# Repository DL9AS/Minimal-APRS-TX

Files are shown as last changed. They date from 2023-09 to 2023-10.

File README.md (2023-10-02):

# Minimal APRS TX by DL9AS

**Note: This project is still in active development. There is no guarantee for full functionality at this time!**

The goal of this project is to provide one of the simplest APRS transmitters. It is especially designed for people who are starting high altitude ballooning. If you are interested in more advanced APRS radiosondes with camera, please have a look at this repository: https://github.com/DL9AS/jufo-project-radiosonde

The PCB requires only five components. The transmitter can be controlled with simple serial commands.

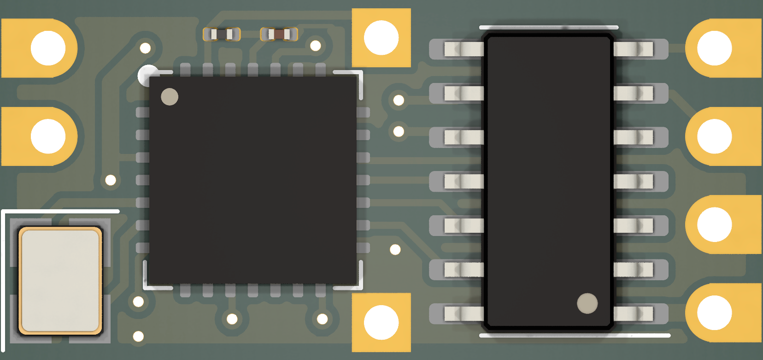
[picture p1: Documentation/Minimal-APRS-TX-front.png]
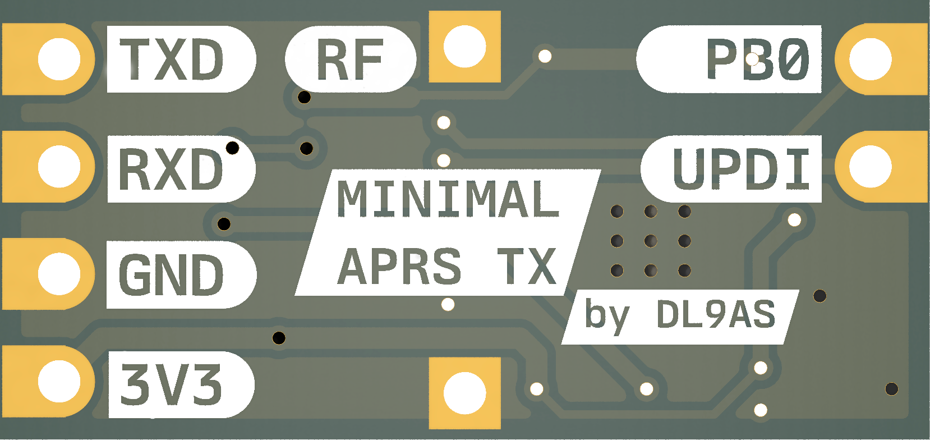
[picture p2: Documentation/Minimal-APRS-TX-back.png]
|  |  |
|:--- |:--- |

## Table of contents

- [Minimal APRS TX by DL9AS](#minimal-aprs-tx-by-dl9as)
  - [Table of contents](#table-of-contents)
  - [Usage](#usage)
    - [`$STAT` *(Get status)*](#stat-get-status)
    - [`$CfgRadio` *(Configure APRS radio)*](#cfgradio-configure-aprs-radio)
    - [`$TxPosPkt` *(Transmit APRS position packet)*](#txpospkt-transmit-aprs-position-packet)
    - [`$TxStatPkt` *(Transmit APRS status packet)*](#txstatpkt-transmit-aprs-status-packet)
  - [PCB Assembly](#pcb-assembly)
  - [Programming](#programming)

## Usage

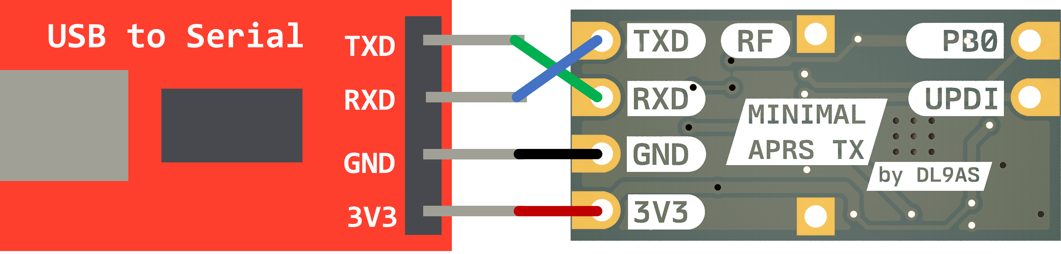
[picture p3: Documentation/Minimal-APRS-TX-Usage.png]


Only a few commands are required to use the Minimal APRS TX module. First the radio is configured with the command `$CfgRadio` and then APRS packets can be sent with the commands `$TXPosPkt` or `$TXStatPkt`.

For communication `9600 Baud` serial with 8 data bits, no parity, one stop bit is used. So it should communicate out of the box with any Arduino.

### `$STAT` *(Get status)*

```
Format:
$STAT;

Return:
[ACK] Minimal APRS TX - V1.0
```

### `$CfgRadio` *(Configure APRS radio)*

```
Format:
$CfgRadio <APRS_Freq>,<APRS_Freq_Err>,<TX_PWR>,<Afsk_Tone>,<Freq_Dev>,<Src_Call>,<Src_ID>,<Digi_Call>,<Digi_SSID>;

Example:
$CfgRadio 144800000,0,17,205,2700,DL9AS,11,WIDE1,1;
```

- `<APRS_Freq>` - APRS frequency in Hz (e.g. `144800000`)
- `<APRS_Freq_Err>` - APRS frequency error/offset in Hz (e.g. `0`)
- `<TX_PWR>` - Transmission power from 2dbm to 20dbm (e.g. `17`)
- `<Afsk_Tone>` - AFSK tone adjustment (e.g. `205`)
- `<Freq_Dev>` - FSK deviation in Hz (e.g. `2700`)
- `<Src_Call>` - APRS source callsign (e.g. `DL9AS`)
- `<Src_ID>` - APRS source SSID (e.g. `11`)
- `<Digi_Call>` - APRS digipeater path callsign (e.g. `WIDE1`)
- `<Digi_SSID>` - APRS digipeater path SSID (e.g. `1`)

### `$TxPosPkt` *(Transmit APRS position packet)*

```
Format:
$TxPosPkt <Lat>,<Long>,<Alt>,<Symbol>,<Symbol_Overlay>,<Comment>;

Example:
$TxPosPkt 525121,133273,42,O,/,"73 from DL9AS";

Resulting APRS packet:
DL9AS-11>AMON,WIDE1-1:!5230.72N/01319.63EO/A=000137/N0T26V31 73 from DL9AS
```

- `<Lat>` - GPS Latitude in deg * 10000 (e.g. `525121`)
- `<Long>` - GPS Longitude in deg * 10000 (e.g. `133273`)
- `<Alt>` - GPS Altitude in meters (e.g. `42`)
- `<Symbol>` - APRS symbol (e.g. `O` for balloon)
- `<Symbol_Overlay>` - APRS symbol overlay (e.g. `/` for balloon)
- `<Comment>` - APRS comment with 50 character max (e.g. `"73 from DL9AS"`)

Note: `(N<Pkt_count>T<Temperature>V<VCC*10>)` is automatically added to the final packet.

### `$TxStatPkt` *(Transmit APRS status packet)*

```
Format:
$TxStatPkt <Comment>;

Example:
$TxStatPkt "73 from DL9AS";

Resulting APRS packet:
DL9AS-1>AMON,WIDE1-1:>N0T0V31 73 from DL9AS
```

- `<Comment>` - APRS comment with 80 character max (e.g. `"73 from DL9AS"`)

Note: `(N<Pkt_count>T<Temperature>V<VCC*10>)` is automatically added to the final packet.

## PCB Assembly

<table>
  <tr>
    <td>In a first step, with the help of the <a href="Hardware/Gerber-Files/">gerber files</a>
, the custom PCBs are ordered from a PCB manufacturer. I would also recommend to order a stencil, that makes the soldering easier.</td>
    <td></td>
  </tr>
</table>

The needed components can now be ordered:

| Designator | Part | Quantity | Price (09.2023) |
| --- | --- | --- | --- |
| U1 | ATTiny1604 | 1 | 0.81$ |
| U2 | SX1278IMLTRT | 1 | 2.65$ |
| X1 | 32MHz Crystal (SMD3225 package) | 1 | 0.15$ |
| C1 | 100nF (0402 package) | 1 | 0.01$ |
| L1 | 200nH (0402 package) | 1 | 0.01$ |

With the PCBs and the components, the transmitter can now be assembled. I would recommend reflow soldering with stencil. It is important that the correct orientation of the ICs is ensured. This [interactive BOM](https://htmlpreview.github.io/?https://github.com/DL9AS/Minimal-APRS-TX/blob/main/Hardware/InteractiveBOM.html) can help with placing the components.

## Programming

Before the Minimal APRS TX module can be used, the ATTiny1604 microcontroller has to be programmed. Here the firmware can be built from the source code or the ready binaries can be used. To keep these instructions as simple as possible, I will describe the second option.

1. First you want to install the `pymcuprog` utility. This requires Python and can be done using `pip install pymcuprog`.  See https://pypi.org/project/pymcuprog/ for more information.
2. Download the correct firmware binary from [here](Software/Binaries/).
3. Connect the USB to serial adapter and install serial drivers if necessary.
4. Run the following command to upload the firmware: 

```
pymcuprog write -d attiny1604 -t uart --erase --verify -u <PORT> -f <FIRMWARE>
```

- `<PORT>` - Serial Port (e.g. `COM5` or `ttyACM0`)
- `<FIRMWARE>` - Firmware file (e.g. `Minimal-APRS-TX_V1.0.hex`)

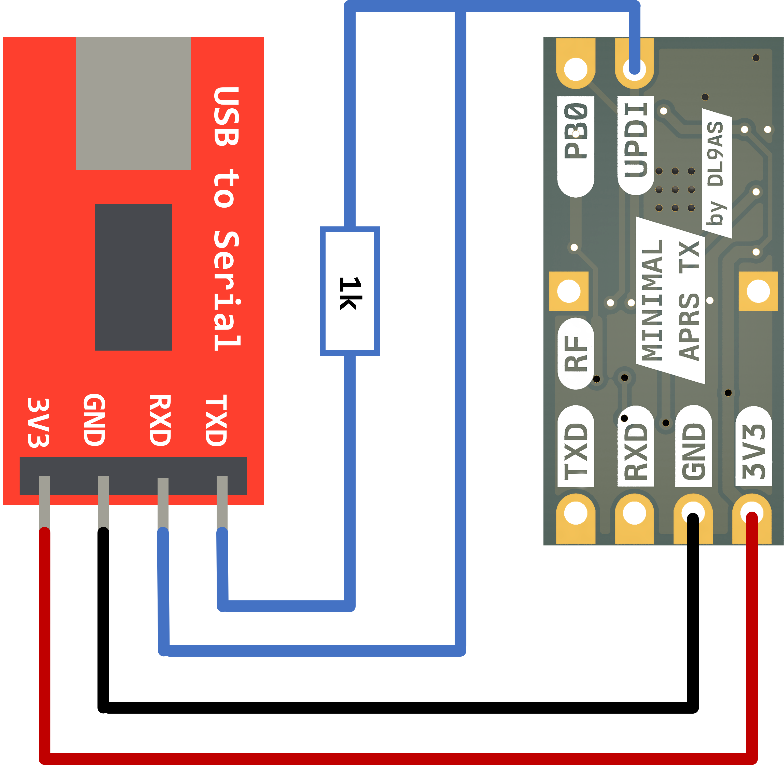
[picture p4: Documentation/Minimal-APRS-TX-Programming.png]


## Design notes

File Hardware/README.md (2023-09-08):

# Minimal APRS TX by DL9AS



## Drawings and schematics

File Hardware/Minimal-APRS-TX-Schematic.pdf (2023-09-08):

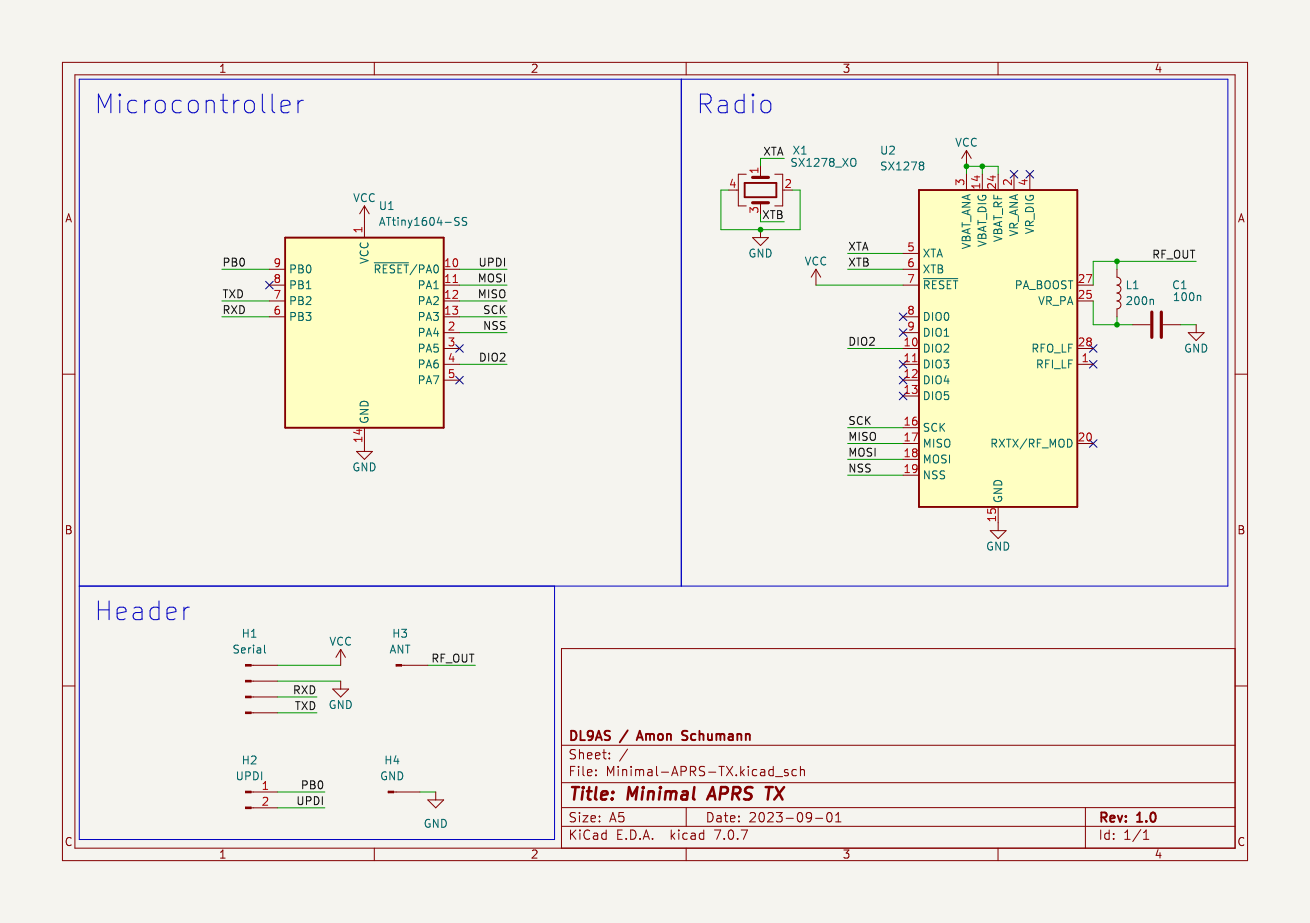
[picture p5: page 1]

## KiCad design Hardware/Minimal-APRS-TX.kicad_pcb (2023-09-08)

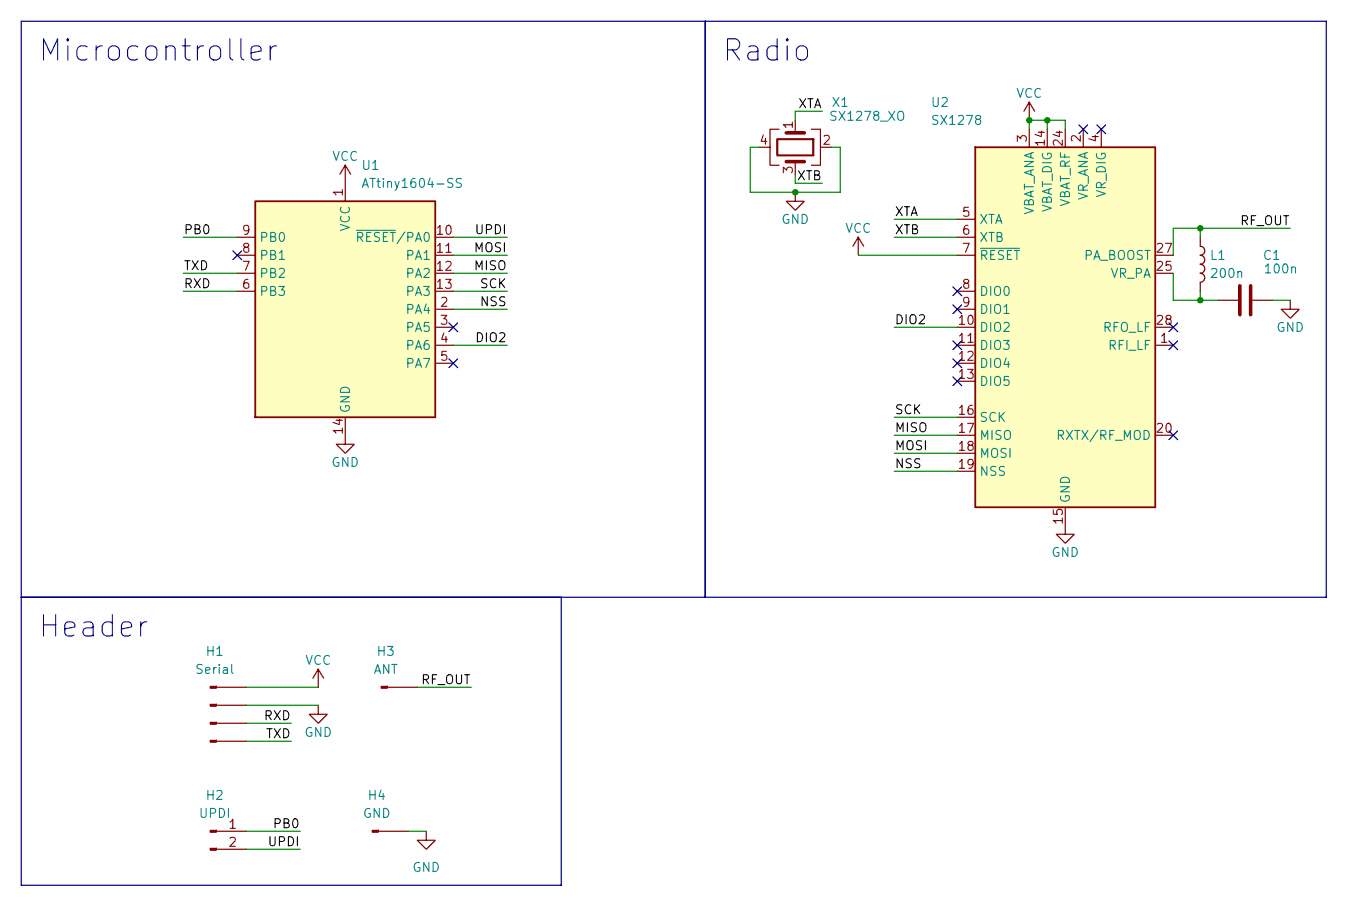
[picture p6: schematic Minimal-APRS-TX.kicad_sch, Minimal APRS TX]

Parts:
C1: 100n; C_0201_0603Metric
H1: Serial; My_PinHeader_4
H2: UPDI; My_PinHeader_2
H3: ANT; My_ANT_Pad
H4: GND; My_ANT_Pad
L1: 200n; L_0201_0603Metric
U1: ATtiny1604-SS; SOIC-14_3.9x8.7mm_P1.27mm
U2: SX1278; QFN-28-1EP_6x6mm_P0.65mm_EP4.8x4.8mm
X1: SX1278_XO; Crystal_SMD_3225-4Pin_3.2x2.5mm

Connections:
/DIO2: U1.4 (PA6), U2.10 (DIO2)
/MISO: U1.12 (PA2), U2.17 (MISO)
/MOSI: U1.11 (PA1), U2.18 (MOSI)
/NSS: U1.2 (PA4), U2.19 (NSS)
/PB0: H2.1, U1.9 (PB0)
/RF_OUT: H3.1, L1.1, U2.27 (PA_BOOST)
/RXD: H1.3, U1.6 (PB3)
/SCK: U1.13 (PA3), U2.16 (SCK)
/TXD: H1.4, U1.7 (PB2)
/UPDI: H2.2, U1.10 (~RESET/PA0)
/XTA: U2.5 (XTA), X1.1
/XTB: U2.6 (XTB), X1.3
GND: C1.2, H1.2, H4.1, U1.14 (GND), U2.15 (GND), U2.21 (GND), U2.22 (GND), U2.23 (GND), U2.26 (GND), U2.29 (GND), X1.2, X1.4
unnamed: C1.1, L1.2, U2.25 (VR_PA)
VCC: H1.1, U1.1 (VCC), U2.3 (VBAT_ANA), U2.7 (~RESET), U2.14 (VBAT_DIG), U2.24 (VBAT_RF)

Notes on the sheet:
Microcontroller
Radio
Header

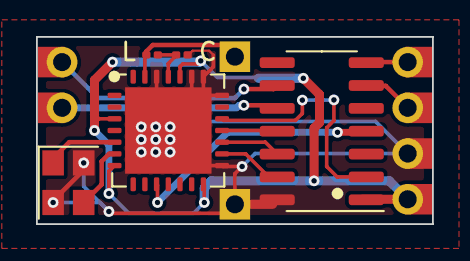
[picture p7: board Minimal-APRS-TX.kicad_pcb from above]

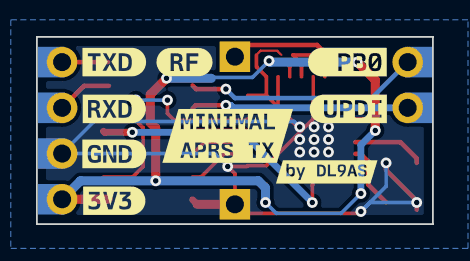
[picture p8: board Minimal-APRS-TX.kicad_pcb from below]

Board: 2 copper layers, 22.0 x 10.4 mm, 18 parts (9 on the bottom side), 15 nets.

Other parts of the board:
kibuzzard-64F1B3B3: G***; kibuzzard-64F1B3B3
kibuzzard-64F1B32F: G***; kibuzzard-64F1B32F
kibuzzard-64F1B34A: G***; kibuzzard-64F1B34A
kibuzzard-64F1B328: G***; kibuzzard-64F1B328
kibuzzard-64F1B334: G***; kibuzzard-64F1B334
kibuzzard-64F1B338: G***; kibuzzard-64F1B338
kibuzzard-64F1B350: G***; kibuzzard-64F1B350
kibuzzard-64F18FB8: G***; kibuzzard-64F18FB8
kibuzzard-64F18FF4: G***; kibuzzard-64F18FF4

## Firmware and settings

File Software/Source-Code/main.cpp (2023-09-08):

/*
 * This file is part of the Minimal APRS TX project.
 * 
 
 * Copyright (C) 2023  Amon Schumann / DL9AS
 
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
 * You should have received a copy of the GNU General Public License
 * along with this program. If not, see <http://www.gnu.org/licenses/>.
 */ 

#include "config.h"
#include "globals.h"
#include "aprs.h"
#include "ax25.h"
#include "SX1278.h"
#include "voltage.h"

// Module globals
uint16_t aprs_packet_counter = 0;

// APRS configuration
uint64_t APRS_freq = SX1278_FREQUENCY;
int32_t APRS_freq_err = SX1278_FREQUENCY_CORRECTION;
uint8_t TX_pwr = SX1278_TX_POWER;
uint32_t FSK_deviation = SX1278_DEVIATION;
char Src_call[8] = APRS_SOURCE_CALLSIGN;
uint8_t Src_ssid = APRS_SOURCE_SSID;
char Digi_call[8] = APRS_DIGIPEATER;
uint8_t Digi_ssid = APRS_DIGIPEATER_SSID;

// APRS Position packets tmp
int32_t latitude = 0;
int32_t longitude = 0;
int32_t altitude = 0;
char latitude_DMH[9];
char longitude_DMH[10];
char comment[81] = "";
char symbol = APRS_SYMBOL;
char symbol_overlay = APRS_SYMBOL_OVERLAY;

// Module functions
void main_generate_aprs_position_packet();
void main_generate_aprs_status_packet();
void convert_gps_coordinates_to_DMH(int32_t gps_latitude, int32_t gps_longitude, char* gps_latitude_DMH, char* gps_longitude_DMH);

void setup()
{
  WDT_INIT;

  // Enable or disable debug serial
  #ifdef DEBUG_SERIAL_ENABLE
    Serial.begin(DEBUG_SERIAL_BAUD_RATE);
  #endif

  // Begin SX1278
  SX1278_begin();

  // Set unused Pins to INPUT_PULLUP for power savings
  pinMode(1, INPUT_PULLUP );
  pinMode(3, INPUT_PULLUP );
  pinMode(6, INPUT_PULLUP );
  pinMode(7, INPUT_PULLUP );
  pinMode(11, INPUT_PULLUP );

  DEBUG_PRINTLN("[STAT]: booted");
}

void loop()
{

  char serial_command_buffer[100]; // TODO: Check size requirements
  memset(serial_command_buffer, '\0', 100);

  while (Serial.available() == false) {WDT_RESET;} // Wait for serial data

  Serial.readBytesUntil(';', serial_command_buffer, 150);

  DEBUG_PRINT("[RCV]: ");
  DEBUG_PRINTLN(serial_command_buffer);

  uint8_t status;

  // Parse $STAT command
  if (!strcmp(serial_command_buffer, "$STAT"))
  {
    DEBUG_PRINTLN("[ACK]: Minimal APRS TX - V1.0");
  }

  // Parse $CfgRadio command
  else if ((status = sscanf(serial_command_buffer, "$CfgRadio %lu,%ld,%hhu,%hhu,%lu,%[^,],%hhu,%[^,],%hhu", &APRS_freq, &APRS_freq_err, &TX_pwr, &AFSK_tone_adj_space, &FSK_deviation, Src_call, &Src_ssid, Digi_call, &Digi_ssid)))
  {
    if(status == 9)
    {
      DEBUG_PRINTLN("[ACK]: valid $CfgRadio");
      AFSK_tone_adj_mark = AFSK_tone_adj_space * 2;
    }
    else
    {
      DEBUG_PRINTLN("[ERR]: invalid $CfgRadio");
    }
  }

  // Parse $TxPosPkt command
  else if ((status = sscanf(serial_command_buffer, "$TxPosPkt %ld,%ld,%ld,%c,%c,\"%[^\"]", &latitude, &longitude, &altitude, &symbol, &symbol_overlay, comment)))
  {
    if(status == 6)
    {
      DEBUG_PRINTLN("[ACK]: valid $TxPosPkt");
      main_generate_aprs_position_packet();
    }
    else
    {
      DEBUG_PRINTLN("[ERR]: invalid $TxPosPkt");
    }
  }

  // Parse $TXStatPkt command
  else if ((status = sscanf(serial_command_buffer, "$TxStatPkt \"%[^\"]", comment)))
  {
    if(status == 1)
    {
      DEBUG_PRINTLN("[ACK]: valid $TXStatPkt");
      main_generate_aprs_status_packet();
    }
    else
    {
      DEBUG_PRINTLN("[ERR]: invalid $TXStatPkt");
    }
  }

  // No valid command found
  else
  {
    DEBUG_PRINTLN("[ERR]: invalid input");
  }
}

/*
* GNSS coordinates format conversion in degrees, minutes and hundredths of a minute (needed for aprs)
* N = north; S = south; E = east; W = west
* more information at: http://www.aprs.org/doc/APRS101.PDF
*/
void convert_gps_coordinates_to_DMH(int32_t gps_latitude, int32_t gps_longitude, char* gps_latitude_DMH, char* gps_longitude_DMH)
{
  int32_t degrees_buffer;
  int32_t minutes_buffer;
  int32_t h_minutes_buffer;
  
  // Calculate latitude

  // Determine whether to append "N" or "S"
  char compass_direction = 'N';
  
  if(gps_latitude < 0)
  {
    gps_latitude = -(gps_latitude);
    compass_direction = 'S';
  }
    
  // Full degrees
  degrees_buffer = gps_latitude/10000;

  // Degree minutes from the remainder
  gps_latitude = gps_latitude - (degrees_buffer*10000);
  gps_latitude = (gps_latitude)*60;
  minutes_buffer = gps_latitude/10000;

  // Hundredths of degree minutes from the remainder
  h_minutes_buffer = (gps_latitude - minutes_buffer*10000)/100;

  // Generate postion data string
  sprintf(gps_latitude_DMH, "%02ld%02ld.%02ld%c" , degrees_buffer, minutes_buffer, h_minutes_buffer, compass_direction);

  // Calculate longitude

  // Determine whether to append "E" or "W"
  compass_direction = 'E';
  
  if(gps_longitude < 0)
  {
    gps_longitude = -(gps_longitude);
    compass_direction = 'W';
  }
  
  // Full degrees
  degrees_buffer = gps_longitude/10000;

  // Degree minutes from the remainder
  gps_longitude = gps_longitude - (degrees_buffer*10000);
  gps_longitude = (gps_longitude)*60;
  minutes_buffer = gps_longitude/10000;

  // Hundredths of degree minutes from the remainder
  h_minutes_buffer = (gps_longitude - minutes_buffer*10000)/100;
  
  // Generate postion data string
  sprintf(gps_longitude_DMH, "%03ld%02ld.%02ld%c" , degrees_buffer, minutes_buffer, h_minutes_buffer, compass_direction);  
}

void main_generate_aprs_position_packet()
{
  // Convert GPS coordinates
  convert_gps_coordinates_to_DMH(latitude, longitude, latitude_DMH, longitude_DMH);

  // Get temperature measurement from SX1278
  SX1278_measure_internal_temperature(&sx1278_internal_last_temp);

  voltage_get_measurements();
  
  char aprs_packet_comment_buf[41];
  sprintf(aprs_packet_comment_buf, "/A=%06ld/N%dT%dV%d|DL9AS MinAPRSTX| ",
  int32_t (altitude * 3.28),
  aprs_packet_counter,
  sx1278_internal_last_temp,
  mcu_voltage);

  // Send APRS packet
  aprs_send_position_packet(&APRS_freq, TX_pwr, FSK_deviation, Src_call, Src_ssid, Digi_call, Digi_ssid, symbol, symbol_overlay, latitude_DMH, longitude_DMH, aprs_packet_comment_buf, comment);

  DEBUG_PRINTLN("[APRS]: PosPkt send");

  // Increment APRS packet counter
  aprs_packet_counter++;
}

void main_generate_aprs_status_packet()
{
  // Convert GPS coordinates
  convert_gps_coordinates_to_DMH(latitude, longitude, latitude_DMH, longitude_DMH);

  // Get temperature measurement from SX1278
  SX1278_measure_internal_temperature(&sx1278_internal_last_temp);
  
  voltage_get_measurements();

  char aprs_packet_info_buf[41];
  sprintf(aprs_packet_info_buf, "N%dT%dV%d|DL9AS MinAPRSTX| ",
  aprs_packet_counter,
  sx1278_internal_last_temp,
  mcu_voltage);

  // Send APRS packet
  aprs_send_status_packet(&APRS_freq, TX_pwr, FSK_deviation, Src_call, Src_ssid, Digi_call, Digi_ssid, aprs_packet_info_buf, comment);

  DEBUG_PRINTLN("[APRS]: StatPkt send");

  // Increment APRS packet counter
  aprs_packet_counter++;
}

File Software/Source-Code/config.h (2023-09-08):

/*
 * This file is part of the Minimal APRS TX project.
 * 
 
 * Copyright (C) 2023  Amon Schumann / DL9AS
 
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
 * You should have received a copy of the GNU General Public License
 * along with this program. If not, see <http://www.gnu.org/licenses/>.
 */ 

#ifndef __CONFIG__H_
#define __CONFIG__H_

#include "defines.h"

/*
 * Target config
 */

  // Choose target:
  // TARGET_MIN_APRS_TX (only target for now)
  #define TARGET TARGET_MIN_APRS_TX 

/*
 * Payload config
 */

  #define WATCHDOG_ENABLE

/*
 * Radio config
 */

  #define SX1278_FREQUENCY 144800000 // Frequency in kHz

  // Set SX1278 NF modulation option
  // MOD_DIO2: use SX1278 DIO2 to generate AFSK modulation
  // MOD_F_HOP: use SX1278 fast frequency hopping to generate AFSK modulation (DIO2 not longer needed)
  #define SX1278_MOD_OPTION MOD_DIO2

  #if SX1278_MOD_OPTION == MOD_DIO2
    #define SX1278_FREQUENCY_CORRECTION -60000 // Frequency offset in Hz
    #define SX1278_TX_POWER 17  // Tx power in dbm (2-20 dbm)
    #define SX1278_DEVIATION 2700 // FSK deviation in Hz
  #elif SX1278_MOD_OPTION == MOD_F_HOP
    #define SX1278_FREQUENCY_CORRECTION -55800 // Frequency offset in Hz
    #define SX1278_TX_POWER 17  // Tx power in dbm (2-20 dbm)
    #define SX1278_DEVIATION 3000 // FSK deviation in Hz
  #endif

  #define SX1278_CRYSTAL_FREQ 32000000 // Crystal frequency in Hz

/*
 * APRS config (defaults)
 */
  
  #define APRS_SOURCE_CALLSIGN "N0CALL"
  #define APRS_SOURCE_SSID 1
  
  #define APRS_DESTINATION_CALLSIGN "AMON"
  #define APRS_DESTINATION_SSID 0
  
  #define APRS_DIGIPEATER "WIDE1"
  #define APRS_DIGIPEATER_SSID 1

  #define APRS_SYMBOL_OVERLAY '/'
  #define APRS_SYMBOL 'O'
   
  #define APRS_FLAGS_AT_BEGINNING 100 // Send x times ax25 flag as TX delay

  // AFSK mark/space length can differ due to inaccurate MCU clock 
  // For DIO2 mod: 408us 1200Hz and 204us 2400Hz good starting point
  // For SX1278 Fhop mod: 390us 1200Hz and 195us 2400Hz good stating point
  #if SX1278_MOD_OPTION == MOD_DIO2
    #define APRS_1200_MARK_DELAY 410 // Send 1200Hz mark for ~833us, so theoretical a delay between state changes of ~417us
    #define APRS_2400_SPACE_DELAY 205 // Send twice 2400Hz space for ~417us each, so theoretical a delay between state changes of ~208us
  #elif SX1278_MOD_OPTION == MOD_F_HOP
    #define APRS_1200_MARK_DELAY 390 // Send 1200Hz mark for ~833us, so theoretical a delay between state changes of ~417us
    #define APRS_2400_SPACE_DELAY 195 // Send twice 2400Hz space for ~417us each, so theoretical a delay between state changes of ~208s
  #endif

  #define APRS_COMMENT_BUF_SIZE 150
 
  #define TEMPERATURE_SENSOR SX1278_INTERNAL // SX1278_INTERNAL (only option for now)
  #define SX1278_INTERNAL_TEMP_OFFSET 15 // Offset in K

/*
 * Serial config
 */

  #define DEBUG_SERIAL_ENABLE

  #define DEBUG_SERIAL_BAUD_RATE 9600
  
#endif

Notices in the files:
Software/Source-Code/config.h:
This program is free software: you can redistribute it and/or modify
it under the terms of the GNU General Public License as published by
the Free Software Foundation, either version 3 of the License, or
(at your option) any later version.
